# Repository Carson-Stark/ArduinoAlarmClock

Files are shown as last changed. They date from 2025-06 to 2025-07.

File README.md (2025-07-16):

# Arduino Multi-Alarm Clock

hero

## Project Overview

A customizable, low-power digital alarm clock built using an **Arduino Nano**. Supports multiple alarms with per-day scheduling, a minimalist two-button interface, and a compact 3D-printed enclosure. Designed for reliability, power efficiency, and an intuitive user experience.

### Features

- Set up to **8 independent alarms** with weekday scheduling
- **16x4 I2C LCD** with large, block-style custom digits
- **Two-button interface** with context-aware short/long presses
- **Ambient light detection** to auto-dim or disable display
- **Deep sleep mode** with RTC interrupt wake every minute
- **AC-powered** with voltage sensing for brownout warnings
- **Compact 3D-printed case** for clean and durable packaging

### Project Timeline

- **Date Started:** September 2018
- **Date Completed:** October 2018

## Demo

https://github.com/user-attachments/assets/caf4f362-8fb0-4f28-ab67-8239f7dfc2e4

## Hardware

| Component | Description |
|---|---|
| Arduino Nano | Microcontroller (ATmega328P) |
| 16x4 LCD (I2C) | Display with custom character support |
| DS3231 RTC | Real-time clock with 1-minute interrupt |
| Photoresistor | Ambient light sensing |
| Piezo buzzer | Audible alarm output |
| Push buttons (x2) | User input interface |
| EEPROM (internal) | Non-volatile alarm data |
| AC adapter (5V) | Power supply |
| Voltage divider | Power voltage monitoring |
| 3D-printed enclosure | Custom case for electronics |

### Circuit Diagram

CircuitDiagram

Public Circuit Designer link: [Alarm Clock Circuit](https://app.cirkitdesigner.com/project/4ae56a12-4e2b-4acc-8b0b-463c14d5e23f)

### Arduino Pins

| Function | Pin | Setting (pinMode) |
|---|-----|---|
| RTC minute‑tick interrupt | 2 | `INPUT_PULLUP` |
| External wake interrupt | 3 | `INPUT_PULLUP` |
| Buzzer output | 5 | `OUTPUT` |
| UI Button A | 11  | `INPUT_PULLUP` |
| UI Button B | 10  | `INPUT_PULLUP` |
| Photo‑resistor ADC | A0  | Analog input |

## Software Overview

- Developed in **Arduino C++** using the Arduino IDE
- LCD and RTC communicate via I2C using `Wire.h`
- Alarm system uses a **weekday bitmask** for flexible scheduling
- Finite State Machine (FSM) handles display and user interaction
- Custom glyphs used to render large-format digits across LCD
- `LowPower.h` enables deep sleep to conserve energy

## Setup & Usage

### 1 · Upload Firmware

1. Open **`AlarmClock.ino`** in the Arduino IDE.  
2. Select **Arduino Nano (ATmega328P, 5 V)** under *Tools → Board*.  
3. Choose the correct **COM port**.  
4. Click **Upload**.

### 2 · Setup Wiring

- Ensure you have connected the required components to the Arduino correctly
- Folow the guide above
- Supply the Circuit with 4.5V DC, recommended to get AC -> DC stepdown converter with barrel plug

### 3 · Interface Controls

| Gesture | Result |
|---|---|
| **Short press A** | Navigate / toggle field |
| **Long press A** | Confirm / enter sub‑mode |
| **Short press B** | Increment / select value |
| **Long press B** | Cancel / back / exit |
| **During alarm – tap** | Snooze 5 min |
| **During alarm – hold B ≈2 s** | Stop alarm until next schedule |
| **Hold B 3s** | Disable/Enable alarm function |

### 4 · Clock Modes

- **Idle:** Large time display + next‑alarm icon
- **Set Time:** Adjust hour/minute
- **Edit Alarm:** Choose index, set time, select weekdays

### 5 · Alarm Flow

1. DS3231 INT triggers every minute → MCU wakes.  
2. Current weekday + time compared to enabled alarm list.  
3. **Match:** Buzzer sounds continuously.  
4. User tap ➜ snooze 5 min; user hold B ➜ stop.  
5. MCU returns to deep sleep until next INT.

## License

MIT License. See `LICENSE` for details.

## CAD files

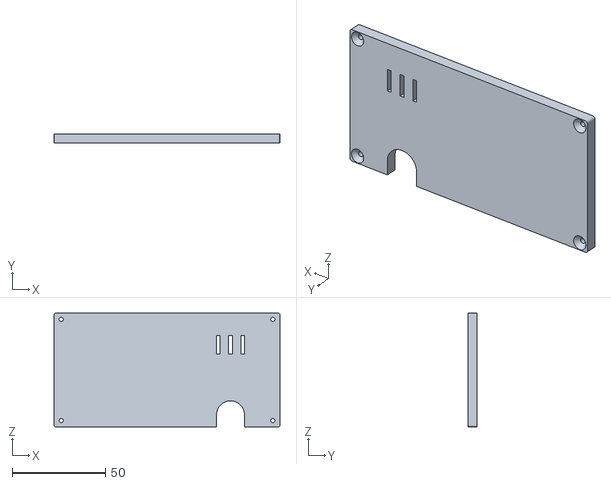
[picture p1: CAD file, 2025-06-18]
enclosure_models/ClockBack.stl
121.0 x 5.00 x 61.0

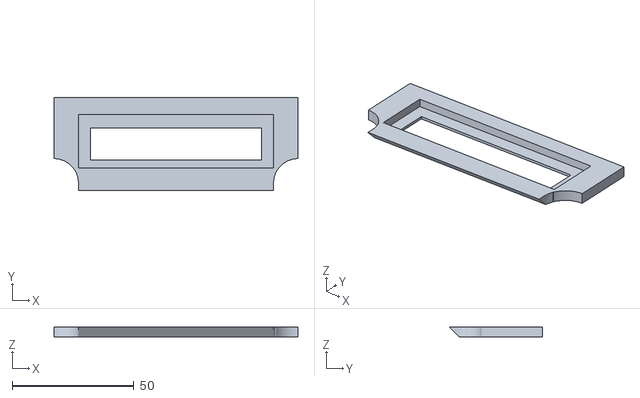
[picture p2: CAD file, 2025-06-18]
enclosure_models/buttons_base.stl
100.0 x 38.0 x 4.10

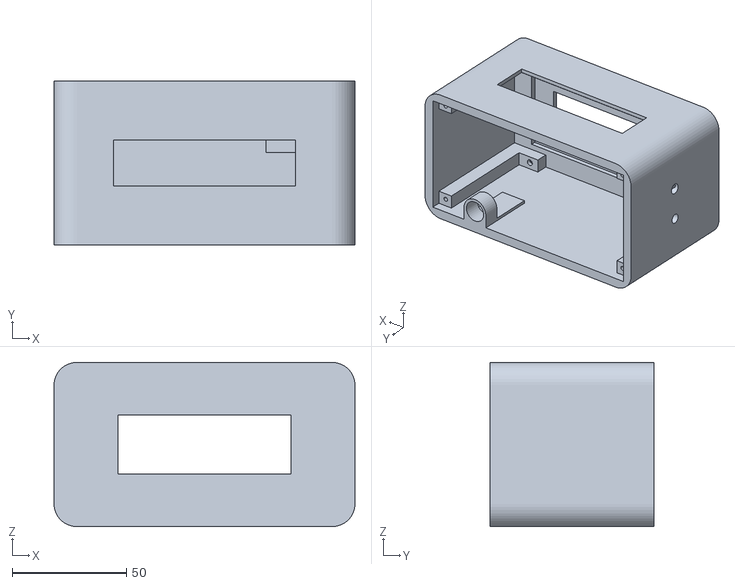
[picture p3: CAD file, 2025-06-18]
enclosure_models/Clock.stl
132.0 x 72.0 x 72.0

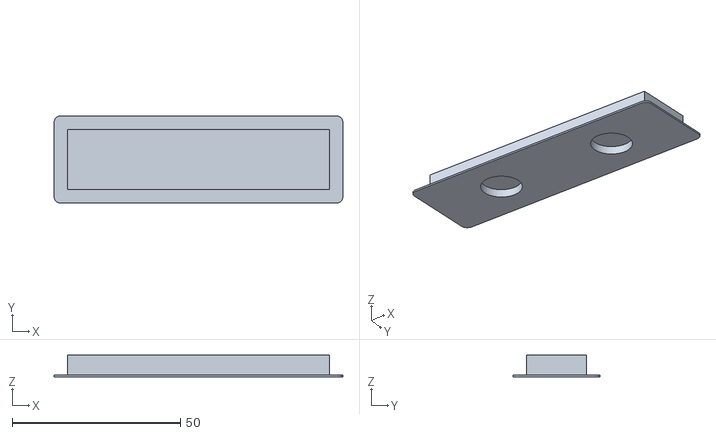
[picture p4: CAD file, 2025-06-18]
enclosure_models/ClockButton.stl
86.0 x 26.0 x 6.46

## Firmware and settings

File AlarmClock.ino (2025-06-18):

//lcd battery powered alarm clock
//features:
//custom character 3 line numbers
//put arduino to sleep to save power
//wakes up every minute to update lcd and check alarms
//ability to set 8 different alarms and the days they are active
//ability to set hour and minute
//wake and light up the screan with button press
//enter set mode with button hold

#include <Arduino.h>
#include <LiquidCrystal_I2C.h>
#include <LowPower.h>
#include <Wire.h>
#include <RTClibExtended.h>

//custom lcd characters
uint8_t smBlockB[8] = {0x0, 0x0, 0x0, 0x1f, 0x1f, 0x1f, 0x1f, 0x1f};
uint8_t smBlockT[8] = {0x1f, 0x1f, 0x1f, 0x1f, 0x1f, 0x0, 0x0, 0x0};
uint8_t halfBlock[8] = {0x0, 0x0, 0x1f, 0x1f, 0x1f, 0x1f, 0x0, 0x0};
uint8_t TRCorner[8] = {0x18, 0x1c, 0x1e, 0x1f, 0x1f, 0x1f, 0x1f, 0x1f};
uint8_t BLCorner[8] = {0x1f, 0x1f, 0x1f, 0x1f, 0x1f, 0xf, 0x7, 0x3};
uint8_t bellNOW[8] = {0x4, 0xe, 0xe, 0xe, 0x1f, 0x0, 0x4, 0x0};
uint8_t bellNXT[8] = {0x4, 0xa, 0xa, 0xa, 0x1f, 0x0, 0x4, 0x0};

//pins
const byte interruptPinRTC = 2;
const byte interruptPinButton = 3;
const byte buzzerPin = 5;
const byte button1 = 11;
const byte button2 = 10;
const int photo = A0;
const int voltage = A1;
const byte readSwitch = 13;
const byte ledSwitch = 12;

const byte lightUpTime = 5;
const byte snoozeTime = 5;

RTC_DS3231 clock;
LiquidCrystal_I2C lcd(0x27, 20, 4);

//alarms
struct alarm
{
    bool days[7];
    byte hour;
    byte minute;
    byte am;

    alarm() {}
    alarm(int h, int m, int a)
    {
        hour = h;
        minute = m;
        am = a;
    }
};
typedef struct alarm Alarm;
Alarm alarms[8];

Alarm currentAlarm;

//standard global variable
bool lightScreen;
byte lightDisTime;
bool displayTime;
bool alarmFlag = false;
bool snoozing;
int snoozeCount = 0;
bool currentAlarmEnabled = true;
bool displayOff = false;
bool setMode;
const char days[8] = "SMTWTFS";

//variables for set mode
byte menu = 0;
byte subMenu = 0;
byte selected = 1;
int previous = 0;
bool on;

//variables for button hold
bool testingButton1;
bool testingButton2;
byte minReleaseTime;
byte minReleaseTime2;

//is the hour AM or PM ?
bool hourIsAM(int hour)
{
    if (hour < 12 || hour == 24)
        return true;

    return false;
}

//conver 24 hour format to 12
int convertHour(int hour)
{
    if (hour > 11 && hour != 12)
        return hour - 12;

    if (hour == 0)
        return 12;

    return hour;
}

//converts 12 hour format to 24
int hourTo24(int hour, bool am)
{
    if (am)
    {
        if (hour == 12)
            return 0;
        return hour;
    }
    else
    {
        if (hour == 12)
            return hour;
        return hour + 12;
    }
}

//gets the number of digits in a number (for printing the date)
int numOfDigits(int number)
{
    int length = 0;
    int temp = 1;
    while (temp <= number)
    {
        length++;
        temp *= 10;
    }
    return length;
}

//print at number spanning 3 lines on the rtc using custom characters
void printLgNum(int num, int column)
{
    lcd.setCursor(column, 0);
    switch (num)
    {
    case 0:
        lcd.write(255);
        lcd.write(0);
        lcd.write(3);
        lcd.setCursor(column, 1);
        lcd.write(255);
        lcd.print(" ");
        lcd.write(255);
        lcd.setCursor(column, 2);
        lcd.write(4);
        lcd.write(1);
        lcd.write(255);
        break;

    case 1:
        lcd.write(0);
        lcd.write(3);
        lcd.print(" ");
        lcd.setCursor(column, 1);
        lcd.print(" ");
        lcd.write(255);
        lcd.print(" ");
        lcd.setCursor(column, 2);
        lcd.write(1);
        lcd.write(255);
        lcd.write(1);
        break;

    case 2:
        lcd.write(0);
        lcd.write(0);
        lcd.write(3);
        lcd.setCursor(column, 1);
        lcd.write(255);
        lcd.write(0);
        lcd.write(0);
        lcd.setCursor(column, 2);
        lcd.write(255);
        lcd.write(1);
        lcd.write(1);
        break;

    case 3:
        lcd.write(0);
        lcd.write(0);
        lcd.write(3);
        lcd.setCursor(column, 1);
        lcd.write(2);
        lcd.write(2);
        lcd.write(255);
        lcd.setCursor(column, 2);
        lcd.write(1);
        lcd.write(1);
        lcd.write(255);
        break;

    case 4:
        lcd.write(255);
        lcd.print(" ");
        lcd.write(255);
        lcd.setCursor(column, 1);
        lcd.write(255);
        lcd.write(1);
        lcd.write(255);
        lcd.setCursor(column, 2);
        lcd.print(" ");
        lcd.print(" ");
        lcd.write(255);
        break;

    case 5:
        lcd.write(255);
        lcd.write(0);
        lcd.write(0);
        lcd.setCursor(column, 1);
        lcd.write(0);
        lcd.write(0);
        lcd.write(3);
        lcd.setCursor(column, 2);
        lcd.write(1);
        lcd.write(1);
        lcd.write(255);
        break;

    case 6:
        lcd.write(255);
        lcd.write(0);
        lcd.write(0);
        lcd.setCursor(column, 1);
        lcd.write(255);
        lcd.write(0);
        lcd.write(3);
        lcd.setCursor(column, 2);
        lcd.write(4);
        lcd.write(1);
        lcd.write(255);
        break;

    case 7:
        lcd.write(0);
        lcd.write(0);
        lcd.write(255);
        lcd.setCursor(column, 1);
        lcd.print(" ");
        lcd.write(255);
        lcd.print(" ");
        lcd.setCursor(column, 2);
        lcd.write(255);
        lcd.print(" ");
        lcd.print(" ");
        break;

    case 8:
        lcd.write(255);
        lcd.write(0);
        lcd.write(3);
        lcd.setCursor(column, 1);
        lcd.write(255);
        lcd.write(2);
        lcd.write(255);
        lcd.setCursor(column, 2);
        lcd.write(4);
        lcd.write(1);
        lcd.write(255);
        break;

    case 9:
        lcd.write(255);
        lcd.write(0);
        lcd.write(3);
        lcd.setCursor(column, 1);
        lcd.write(4);
        lcd.write(1);
        lcd.write(255);
        lcd.setCursor(column, 2);
        lcd.print(" ");
        lcd.print(" ");
        lcd.write(255);
        break;
    }
}

//print a large colon using custom characters
void printLgColon(int column)
{
    lcd.setCursor(column, 0);
    lcd.write(1);
    lcd.setCursor(column, 2);
    lcd.write(0);
}

//erases a block of text by printing spaces
void eraseBlock(int column, int row, int height, int length)
{
    for (int h = row; h < row + height; h++)
    {
        lcd.setCursor(column, h);
        for (int l = column; l < column + length; l++)
        {
            lcd.print(" ");
        }
    }
}

//prints the hour (centers it based on the number of digits in the hour)
void printHour(int hour)
{
    if (hour < 10)
        printLgNum(hour % 10, 3);
    else
    {
        printLgNum(hour / 10, 1);
        printLgNum(hour % 10, 5);
    }
}

//prints the minute (centers it based on the number of digits in the hour)
void printMinute(int minute, int hour)
{
    if (hour < 10)
    {
        printLgNum(minute / 10, 9);
        printLgNum(minute % 10, 13);
    }
    else
    {
        printLgNum(minute / 10, 11);
        printLgNum(minute % 10, 15);
    }
}

//prints AM or PM (centers it based on the number of digits in the hour)
void printAM(int hour, bool am)
{
    if (hour < 10)
    {
        lcd.setCursor(17, 0);
        lcd.print(am ? "A" : "P");
        lcd.setCursor(17, 1);
    }
    else
    {
        lcd.setCursor(19, 0);
        lcd.print(am ? "A" : "P");
        lcd.setCursor(19, 1);
    }
    lcd.print("M");
}

//prints the colon (centers it based on the number of digits in the hour)
void printColon(int hour)
{
    if (hour < 10)
        printLgColon(7);
    else
        printLgColon(9);
}

//prints the time using previous functions (h:mm AM/PM)
void printTime(bool reset)
{
    int h = convertHour(clock.now().hour());
    int m = clock.now().minute();

    if (reset || ((h == 10 || h == 1) && m == 0))
    {
        eraseBlock(0, 0, 3, 19);
        printColon(h);
    }
    if (reset || m == 0)
        printHour(h);
    if (reset || ((h == 10 || h == 1) && m == 0) || (h == 12 && m == 0))
    {
        eraseBlock(19, 0, 2, 1);
        printAM(h, hourIsAM(clock.now().hour()));
    }

    printMinute(m, h);
}

bool timeEarlierThan(int h1, int m1, int h2, int m2)
{
    if (h1 < h2)
        return true;

    if (h1 == h2 && m1 < m2)
        return true;

    return false;
}

//prints the current alarm ([bell]h:mm AM/PM)
void printAlarm()
{
    eraseBlock(0, 3, 1, 8);
    lcd.setCursor(0, 3);

    if ((currentAlarm.days[clock.now().dayOfTheWeek() < 6 ? clock.now().dayOfTheWeek() + 1 : 0] || (currentAlarm.days[clock.now().dayOfTheWeek()] && timeEarlierThan(clock.now().hour(), clock.now().minute(), hourTo24(currentAlarm.hour, currentAlarm.am == 1 ? true : false), currentAlarm.minute))) && currentAlarm.am > 0)
    {
        if (!currentAlarmEnabled)
        {
            lcd.write(5);
            lcd.print("OFF");
            return;
        }

        if (currentAlarm.days[clock.now().dayOfTheWeek()] && timeEarlierThan(clock.now().hour(), clock.now().minute(), hourTo24(currentAlarm.hour, currentAlarm.am == 1 ? true : false), currentAlarm.minute))
            lcd.write(5);
        else
            lcd.write(6);

        lcd.print(currentAlarm.hour);
        lcd.print(":");
        if (currentAlarm.minute < 10)
            lcd.print(0);
        lcd.print(currentAlarm.minute);
        lcd.print(currentAlarm.am == 1 ? "AM" : "PM");
    }
    else
    {
        if (!currentAlarmEnabled)
        {
            lcd.write(6);
            lcd.print("OFF");
            return;
        }

        lcd.write(6);
        lcd.print("NONE");
    }
}

//prints the day on the screen (wd d/m/yy)
void printDay()
{
    eraseBlock(9, 3, 1, 11);

    int totalDigits = numOfDigits(clock.now().month()) + numOfDigits(clock.now().day());
    if (totalDigits == 4)
        lcd.setCursor(9, 3);
    else if (totalDigits == 3)
        lcd.setCursor(10, 3);
    else
        lcd.setCursor(11, 3);

    int day = clock.now().dayOfTheWeek();
    if (day == 1)
        lcd.print("MO");
    else if (day == 2)
        lcd.print("TU");
    else if (day == 3)
        lcd.print("WE");
    else if (day == 4)
        lcd.print("TH");
    else if (day == 5)
        lcd.print("FR");
    else if (day == 6)
        lcd.print("SA");
    else if (day == 0)
        lcd.print("SU");

    lcd.print(" ");
    lcd.print(clock.now().month());
    lcd.print("/");
    lcd.print(clock.now().day());
    lcd.print("/");
    lcd.print(clock.now().year() - 2000);
}

//used for setting the alarms : prints a certain alarm and the days its enabled
//#) h:mm AM/PM/OFF smtwtfs
void printAlarmSet(int row, int alarmIndex)
{
    eraseBlock(0, row, 1, 20);
    Alarm a = alarms[alarmIndex];

    //print number
    lcd.setCursor(0, row);
    lcd.print(alarmIndex + 1);
    lcd.print(") ");

    //print alarm
    lcd.print(a.hour);
    lcd.print(":");
    lcd.print(a.minute / 10);
    lcd.print(a.minute % 10);
    lcd.print(" ");
    if (a.am == 0)
        lcd.print("OFF");
    else if (a.am == 1)
        lcd.print("AM");
    else
        lcd.print("PM");

    //print days to enable on
    lcd.setCursor(13, row);
    for (int i = 0; i < 7; i++)
    {
        if (a.days[i])
            lcd.print(days[i]);
        else
            lcd.write(tolower(days[i]));
    }
}

//set the rtc, clear alarms, reactivate alarm for every minute
void setClock(DateTime datetime)
{
    clock.armAlarm(1, false);
    clock.clearAlarm(1);
    clock.alarmInterrupt(1, false);
    clock.armAlarm(2, false);
    clock.clearAlarm(2);
    clock.alarmInterrupt(2, false);

    clock.adjust(datetime);
    clock.setAlarm(ALM2_EVERY_MINUTE, 0, 0, 0);
    clock.alarmInterrupt(2, true);
}

//sets the current alarm to correct one : first searches current day then the next day
void findNextAlarm()
{
    int lowestH = 80;
    int lowestM = 60;
    bool foundNext;

    for (int i = 0; i < 8; i++)
    {
        if (alarms[i].am > 0)
        {
            int h = 100;
            if (alarms[i].days[clock.now().dayOfTheWeek()] && !timeEarlierThan(hourTo24(alarms[i].hour, alarms[i].am == 1 ? true : false), alarms[i].minute, clock.now().hour(), clock.now().minute()))
                h = hourTo24(alarms[i].hour, alarms[i].am == 1 ? true : false);
            else if (alarms[i].days[clock.now().dayOfTheWeek() < 6 ? clock.now().dayOfTheWeek() + 1 : 0])
                h = hourTo24(alarms[i].hour, alarms[i].am == 1 ? true : false) + 24;

            if (h < lowestH || (h == lowestH && alarms[i].minute < lowestM))
            {
                lowestH = h;
                lowestM = alarms[i].minute;
                currentAlarm = alarms[i];
                foundNext = true;
            }
        }
    }

    if (!foundNext)
        currentAlarm = alarms[0];
}

//attached to interrupt by button
void wakeUpButton()
{
}

//attached to interrupt by rtc
void wakeUpRTC()
{
    displayTime = true;
}

//used to check if a certain amount of time has passed since a preious time
//used for blinking text
bool passedInterval(int previous, int interval)
{
    if (previous > millis() % 10000)
        return (10000 - previous) + millis() % 10000 > interval;
    else
        return millis() % 10000 - previous > interval;
}

void setup()
{
    pinMode(interruptPinRTC, INPUT_PULLUP);
    pinMode(interruptPinButton, INPUT_PULLUP);
    pinMode(button1, INPUT_PULLUP);
    pinMode(button2, INPUT_PULLUP);
    pinMode(buzzerPin, OUTPUT);
    pinMode(photo, INPUT_PULLUP);
    //pinMode(voltage, INPUT);
    pinMode(readSwitch, OUTPUT);

    //signals successful start
    digitalWrite(LED_BUILTIN, HIGH);
    delay(5000);
    digitalWrite(LED_BUILTIN, LOW);

    Serial.begin(9600);
    Wire.begin();
    clock.begin();
    lcd.init();

    //custom characters for lcd
    lcd.createChar(0, smBlockT);
    lcd.createChar(1, smBlockB);
    lcd.createChar(2, halfBlock);
    lcd.createChar(3, TRCorner);
    lcd.createChar(4, BLCorner);
    lcd.createChar(5, bellNOW);
    lcd.createChar(6, bellNXT);
    lcd.home();

    //sets time to upload time
    clock.writeSqwPinMode(DS3231_OFF);
    //setClock(DateTime(__DATE__, __TIME__));

    for (int i = 0; i < 8; i++)
    {
        alarms[i] = Alarm(8, 0, 0);
    }
    currentAlarm = alarms[0];
    findNextAlarm(); //<-- sets the current alarm to correct one

    printTime(true);
    printAlarm();
    printDay();
}

//puts arduino to sleep and attaches correct interrupts
void sleep()
{
    attachInterrupt(0, wakeUpRTC, LOW);
    attachInterrupt(1, wakeUpButton, LOW);
    LowPower.powerDown(SLEEP_FOREVER, ADC_OFF, BOD_OFF);

    Serial.print("wake");
    detachInterrupt(0);
    detachInterrupt(1);
    clock.clearAlarm(2);
    if (!displayTime)
    {
        digitalWrite(readSwitch, HIGH);
        delay(10);

        if (displayOff)
        {
            displayOff = false;
            lcd.display();
        }

        if (analogRead(photo) > 900)
        {
            int sec = clock.now().second();
            lightScreen = true;
            lightDisTime = sec + lightUpTime < 60 ? sec + lightUpTime : sec + lightUpTime - 60;
            lcd.backlight();
        }

        if (analogRead(voltage) * (3.3 / 1023) < 0.25)
        {
            lcd.clear();
            lcd.setCursor(1, 4);
            lcd.print("LOW BATTERY:");
            lcd.setCursor(2, 5);
            lcd.print(analogRead(voltage) * (3.33 / 1023) * 2);
            lcd.print("V ");
            lcd.print(analogRead(voltage) * (3.33 / 1023) / 2.25 * 100);
            lcd.print("%");

            delay(3000);

            printTime(true);
            printAlarm();
            printDay();
        }

        delay(10);
        digitalWrite(readSwitch, LOW);
    }
}

//variables for loop()
bool buttonHeld;
bool buttonHeld2;
byte newHour;
byte newMinute;
bool am;
byte newMonth;
byte newDay;
byte newYear;
bool ready;
int lastInteraction;
bool tempDis;
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

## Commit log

2025-06-18 added model files
    [Clock.stl, ClockBack.stl, ClockButton.stl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]
2025-06-18 rename folder
    [Clock.stl, ClockBack.stl, ClockButton.stl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]
